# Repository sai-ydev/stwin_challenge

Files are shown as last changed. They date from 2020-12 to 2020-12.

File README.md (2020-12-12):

# STWIN Challenge submission - Low-Cost Sensor Hub for Anomaly Detection

This repo contains all the relevant information for our submission to the STWIN Challenge.

The Sensor Hub has the following variants: 

* Zigbee variant (Battery Powered)
  * ISM330DHCX
  * IIS2ICLX 
* Cellular variant (DC powered)
  * ISM330DHCX
  
## Applications

* Asset Tracking
* Anomaly Detection

## Project log - 12/11/2020

PCBs have arrived

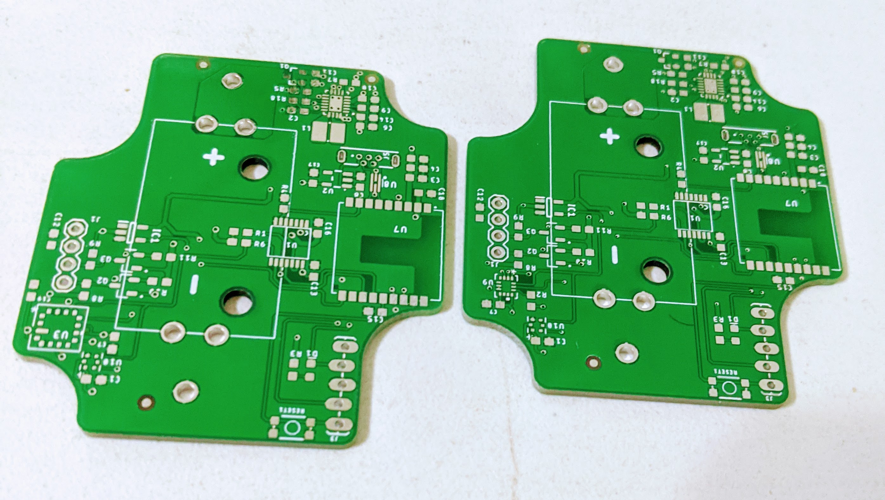
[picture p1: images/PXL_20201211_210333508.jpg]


## Project Log - 12/6/2020

PCBs sent to fabrication

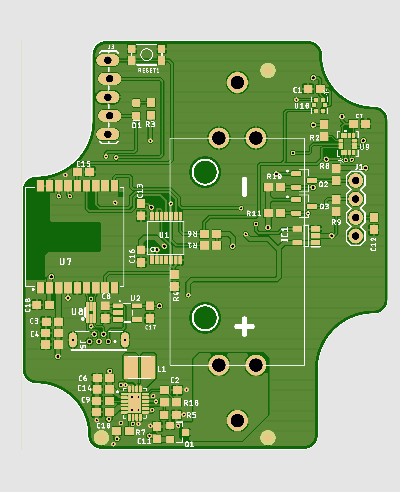
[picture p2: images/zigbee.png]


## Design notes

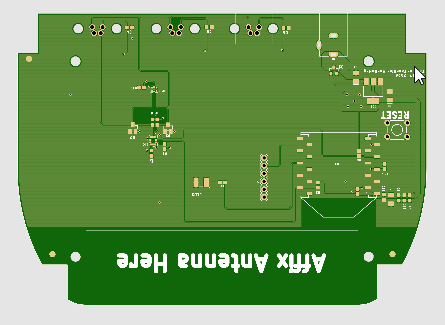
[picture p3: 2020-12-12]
images/cellular.png

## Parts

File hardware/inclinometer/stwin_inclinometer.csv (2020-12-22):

Part | Value | Device | Package | Description | AVAILABILITY | BUILT_BY | COPYRIGHT | DATASHEET | DESCRIPTION | DIGI-KEY_PART_NUMBER | HEIGHT | MANUFACTURER_NAME | MANUFACTURER_PART_NUMBER | MF | MOUSER_PART_NUMBER | MOUSER_PRICE-STOCK | MP | PACKAGE | PRICE | PROD_ID | PURCHASE-URL | SOURCELIBRARY | VALUE | VENDOR
BATT1 | KEYSTONE_54KEYSTONE_2 | KEYSTONE_54KEYSTONE_2 | KEYSTONE_V2
C1 | 0.1uF | 0.1UF-0603-25V-(+80/-20%) | 0603 | 0.1µF ceramic capacitors |  |  |  |  |  |  |  |  |  |  |  |  |  |  |  | CAP-00810 |  |  | 0.1uF
C2 | 10uF | 10UF-0603-6.3V-20% | 0603 | 10.0µF ceramic capacitors |  |  |  |  |  |  |  |  |  |  |  |  |  |  |  | CAP-11015 |  |  | 10uF
C3 | 560pF | 560PF-0603-50V-5% | 0603 | 0.56nF/560pF ceramic capacitors |  |  |  |  |  |  |  |  |  |  |  |  |  |  |  | CAP-08749 |  |  | 560pF
C4 | 10uF | 10UF-0603-6.3V-20% | 0603 | 10.0µF ceramic capacitors |  |  |  |  |  |  |  |  |  |  |  |  |  |  |  | CAP-11015 |  |  | 10uF
C5 | 10nF | 10NF-0603-50V-10% | 0603 | 0.01uF/10nF/10,000pF ceramic capacitors |  |  |  |  |  |  |  |  |  |  |  |  |  |  |  | CAP-00867 |  |  | 10nF
C6 | 10pF | 10PF-0603-50V-5% | 0603 | 10pF ceramic capacitors |  |  |  |  |  |  |  |  |  |  |  |  |  |  |  | CAP-11812 |  |  | 10pF
C7 | 0.1uF | 0.1UF-0603-25V-(+80/-20%) | 0603 | 0.1µF ceramic capacitors |  |  |  |  |  |  |  |  |  |  |  |  |  |  |  | CAP-00810 |  |  | 0.1uF
C8 | 1.0uF | 1.0UF-0603-16V-10% | 0603 | 1µF ceramic capacitors |  |  |  |  |  |  |  |  |  |  |  |  |  |  |  | CAP-00868 |  |  | 1.0uF
C9 | 2.2uF | 2.2UF-0603-10V-20% | 0603 | 2.2µF ceramic capacitors |  |  |  |  |  |  |  |  |  |  |  |  |  |  |  | CAP-07888 |  |  | 2.2uF
C10 | 10nF | 10NF-0603-50V-10% | 0603 | 0.01uF/10nF/10,000pF ceramic capacitors |  |  |  |  |  |  |  |  |  |  |  |  |  |  |  | CAP-00867 |  |  | 10nF
C11 | 47uF | 4.7UF0603 | 0603 | 4.7µF ceramic capacitors |  |  |  |  |  |  |  |  |  |  |  |  |  |  |  | CAP-08280 |  |  | 4.7uF
C12 | 0.1uF | 0.1UF-0603-25V-(+80/-20%) | 0603 | 0.1µF ceramic capacitors |  |  |  |  |  |  |  |  |  |  |  |  |  |  |  | CAP-00810 |  |  | 0.1uF
C13 | 0.1uF | 0.1UF-0603-25V-(+80/-20%) | 0603 | 0.1µF ceramic capacitors |  |  |  |  |  |  |  |  |  |  |  |  |  |  |  | CAP-00810 |  |  | 0.1uF
C14 | 47uF | 4.7UF0603 | 0603 | 4.7µF ceramic capacitors |  |  |  |  |  |  |  |  |  |  |  |  |  |  |  | CAP-08280 |  |  | 4.7uF
C15 | 10nF | 10NF-0603-50V-10% | 0603 | 0.01uF/10nF/10,000pF ceramic capacitors |  |  |  |  |  |  |  |  |  |  |  |  |  |  |  | CAP-00867 |  |  | 10nF
C16 | 0.1uF | 0.1UF-0603-25V-(+80/-20%) | 0603 | 0.1µF ceramic capacitors |  |  |  |  |  |  |  |  |  |  |  |  |  |  |  | CAP-00810 |  |  | 0.1uF
C17 | 1.0uF | 1.0UF-0603-16V-10% | 0603 | 1µF ceramic capacitors |  |  |  |  |  |  |  |  |  |  |  |  |  |  |  | CAP-00868 |  |  | 1.0uF
C18 | 1.0uF | 1.0UF-0603-16V-10% | 0603 | 1µF ceramic capacitors |  |  |  |  |  |  |  |  |  |  |  |  |  |  |  | CAP-00868 |  |  | 1.0uF
C19 | 0.1uF | 0.1UF-0603-25V-(+80/-20%) | 0603 | 0.1µF ceramic capacitors |  |  |  |  |  |  |  |  |  |  |  |  |  |  |  | CAP-00810 |  |  | 0.1uF
D1 | GREEN | LED-GREEN0603 | LED-0603 | Green SMD LED |  |  |  |  |  |  |  |  |  |  |  |  |  |  |  | DIO-00821 |  |  | GREEN
IC1 | NC7SZ66M5X | NC7SZ66M5X | SOT95P280X145-5N | NC7SZ66M5X, Analogue SPST Switch Single SPST, 3 V, 5 V, 5-Pin, SOT-23, 1 |  |  |  |  | NC7SZ66M5X, Analogue SPST Switch Single SPST, 3 V, 5 V, 5-Pin, SOT-23, 1 |  | 1.45mm | ON Semiconductor | NC7SZ66M5X |  | 512-NC7SZ66M5X | https://www.mouser.com/Search/Refine.aspx?Keyword=512-NC7SZ66M5X
J1 |  | I2C_STANDARD | 1X04 | SparkFun I2C Standard Pinout Header
J3 |  | CONN_05LOCK_LONGPADS | 1X05_LOCK_LONGPADS | Multi connection point. Often used as Generic Header-pin footprint for 0.1 inch spaced/style header connections
J5 | 614105150721 | 614105150721 | 614105150721 | WR-COM Micro USB 2.0 Type B Vertical 5 Contacts |  |  |  |  | USB - micro B USB 2.0 Receptacle Connector 5 Position Through Hole |  |  |  |  | Wurth Electronics |  |  | 614105150721 | None |  |  | https://pricing.snapeda.com/search/part/614105150721/?ref=eda
L1 | LQH3NPN100MMEL | LQH3NPN100MMEL | INDPM3030X150N | Fixed Inductors 10uH 1280mA 0.228ohm SRF=20MHz(min) |  |  |  |  | Fixed Inductors 10uH 1280mA 0.228ohm SRF=20MHz(min) |  | 1.5mm | Murata Electronics | LQH3NPN100MMEL |  | 81-LQH3NPN100MMEL | https://www.mouser.com/Search/Refine.aspx?Keyword=81-LQH3NPN100MMEL
Q1 | 2.5A/30V/105mΩ | MOSFET_PCH-DMG2307L | SOT23-3 | P-channel MOSFETs |  |  |  |  |  |  |  |  |  |  |  |  |  |  |  | TRANS-11308 |  |  | 2.5A/30V/105mΩ
Q2 | BSS138 | BSS138 | SOT95P240X111-3N | N-Channel 50V 220mA (Ta) 360mW (Ta) Surface Mount SOT-23-3 Check prices | Good |  |  |  | N-Channel 50V 220mA (Ta) 360mW (Ta) Surface Mount SOT-23-3 |  |  |  |  | ON Semiconductor |  |  | BSS138 | SOT-23 ON Semiconductor | None |  | https://pricing.snapeda.com/search/part/BSS138/?ref=eda
Q3 | BSS138 | BSS138 | SOT95P240X111-3N | N-Channel 50V 220mA (Ta) 360mW (Ta) Surface Mount SOT-23-3 Check prices | Good |  |  |  | N-Channel 50V 220mA (Ta) 360mW (Ta) Surface Mount SOT-23-3 |  |  |  |  | ON Semiconductor |  |  | BSS138 | SOT-23 ON Semiconductor | None |  | https://pricing.snapeda.com/search/part/BSS138/?ref=eda
R1 | 4.7k | 4.7KOHM-0603-1/10W-1% | 0603 | 4.7kΩ resistor |  |  |  |  |  |  |  |  |  |  |  |  |  |  |  | RES-07857 |  |  | 4.7k
R3 | 1k | 1KOHM-0603-1/10W-1% | 0603 | 1kΩ resistor |  |  |  |  |  |  |  |  |  |  |  |  |  |  |  | RES-07856 |  |  | 1k
R4 | 10M | 10MOHM-0603-1/10W-5% | 0603 | RES-09327 |  |  |  |  |  |  |  |  |  |  |  |  |  |  |  | RES-08283 |  |  | 10M
R5 | 365k | 348KOHM-0603-1/10W-1% | 0603 | 348kΩ resistor |  |  |  |  |  |  |  |  |  |  |  |  |  |  |  | RES-12533 |  |  | 348k
R6 | 4.7k | 4.7KOHM-0603-1/10W-1% | 0603 | 4.7kΩ resistor |  |  |  |  |  |  |  |  |  |  |  |  |  |  |  | RES-07857 |  |  | 4.7k
R7 | 10M | 10MOHM-0603-1/10W-5% | 0603 | RES-09327 |  |  |  |  |  |  |  |  |  |  |  |  |  |  |  | RES-08283 |  |  | 10M
R8 | 4.7k | 4.7KOHM-0603-1/10W-1% | 0603 | 4.7kΩ resistor |  |  |  |  |  |  |  |  |  |  |  |  |  |  |  | RES-07857 |  |  | 4.7k
R9 | 4.7k | 4.7KOHM-0603-1/10W-1% | 0603 | 4.7kΩ resistor |  |  |  |  |  |  |  |  |  |  |  |  |  |  |  | RES-07857 |  |  | 4.7k
R10 | 4.7k | 4.7KOHM-0603-1/10W-1% | 0603 | 4.7kΩ resistor |  |  |  |  |  |  |  |  |  |  |  |  |  |  |  | RES-07857 |  |  | 4.7k
R11 | 4.7k | 4.7KOHM-0603-1/10W-1% | 0603 | 4.7kΩ resistor |  |  |  |  |  |  |  |  |  |  |  |  |  |  |  | RES-07857 |  |  | 4.7k
R18 | 2M | 1MOHM-0603-1/4W-5% | 0603 | 1MΩ resistor |  |  |  |  |  |  |  |  |  |  |  |  |  |  |  | RES-07868 |  |  | 1M
RESET1 |  | MOMENTARY-SWITCH-SPST-2-SMD-4.6X2.8MM | TACTILE_SWITCH_SMD_4.6X2.8MM | Momentary Switch (Pushbutton) - SPST - Two Circuits |  |  |  |  |  |  |  |  |  |  |  |  |  |  |  | SWCH-13065
U$5 | FIDUCIAL | FIDUCIAL | FIDUCIAL_1MM | For use by pick and place machines to calibrate the vision/machine, 1mm
U$6 | FIDUCIAL | FIDUCIAL | FIDUCIAL_1MM | For use by pick and place machines to calibrate the vision/machine, 1mm
U$7 | FIDUCIAL | FIDUCIAL | FIDUCIAL_1MM | For use by pick and place machines to calibrate the vision/machine, 1mm
U1 | TS3A4751 | TS3A4751 | 14_PIN | TS3A4751 Quad Switch | Unavailable |  |  |  | 0.9 Ohm Low-Voltage Single-Supply Quad SPST Analog Switch |  |  |  |  | Texas Instruments |  |  | TS3A4751 | TSSOP-14 Texas Instruments | None
U2 | 3.3V | V_REG_AP2112K-3.3V | SOT23-5 | AP2112 - 600mA CMOS LDO Regulator w/ Enable |  |  |  |  |  |  |  |  |  |  |  |  |  |  |  | VREG-12457 |  |  | 3.3V
U3 | IIS2ICLXTR | IIS2ICLXTR | QFN_ICLX_STM |  |  | EMA_Matt | Copyright (C) 2018 Accelerated Designs. All rights reserved | https://www.st.com/resource/en/datasheet/iis2iclx.pdf |  |  |  |  | IIS2ICLXTR |  |  |  |  |  |  |  |  | Updates_to_database_2020-11-03 |  | STMicroelectronics
U4 | LTC3106EUDC#TRPBF | LTC3106EUDC#TRPBF | QFN50P400X300X80-21N | LTC3106 - 300mA Low Voltage Buck-Boost Converter with PowerPath and 1.6μA Quiescent Current | Unavailable |  |  |  | LTC3106 - 300mA Low Voltage Buck-Boost Converter with PowerPath and 1.6μA Quiescent Current |  |  |  |  | Linear Technology/Analog |  |  | LTC3106EUDC#TRPBF | QFN-20 Linear Technology | None
U7 | STEVAL-STLCS01V1 | STEVAL-STLCS01V1 | XDCR_STEVAL-STLCS01V1 | Evaluation kit based on the STM32L476JGY6TR, LSM303AGRTR, LSM6DSMTR, BlueNRG-MSCSP, LPS22HBTR, MP34DT04 and BALF-NRG | Unavailable |  |  |  | BlueNRG-MS, LPS22HB, LSM6DSM, LSM303AGR, MP34DT04, STM32L4 SensorTile Accelerometer, Gyroscope, Humidity, Magnetometer, Pressure, Temperature Sensor Evaluation Board |  |  |  |  | STMicroelectronics |  |  | STEVAL-STLCS01V1 | None | None
U8 | USBLC6-2 | USBLC6-2 | USBLC6-2P6 |  | Unavailable |  |  |  | 17V Clamp 5A (8/20µs) Ipp Tvs Diode Surface Mount SOT-23-6 |  |  |  |  | STMicroelectronics |  |  | USBLC6-2 | SOT-563 STMicroelectronics | None
U10 | HTS221TRHLGA-6L_2X2_STM-M | HTS221TRHLGA-6L_2X2_STM-M | HLGA-6L_2X2_STM-M |  |  | EMA_Anthony | Copyright (C) 2018 Accelerated Designs. All rights reserved | https://www.st.com/content/ccc/resource/technical/document/datasheet/4d/9a/9c/ad/25/07/42/34/DM00116291.pdf/files/DM00116291.pdf/jcr:content/translations/en.D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 |  |  |  |  | HTS221TR |  |  |  |  |  |  |  |  | Updates_to_database_2020-11-03 |  | STMicroelectronics

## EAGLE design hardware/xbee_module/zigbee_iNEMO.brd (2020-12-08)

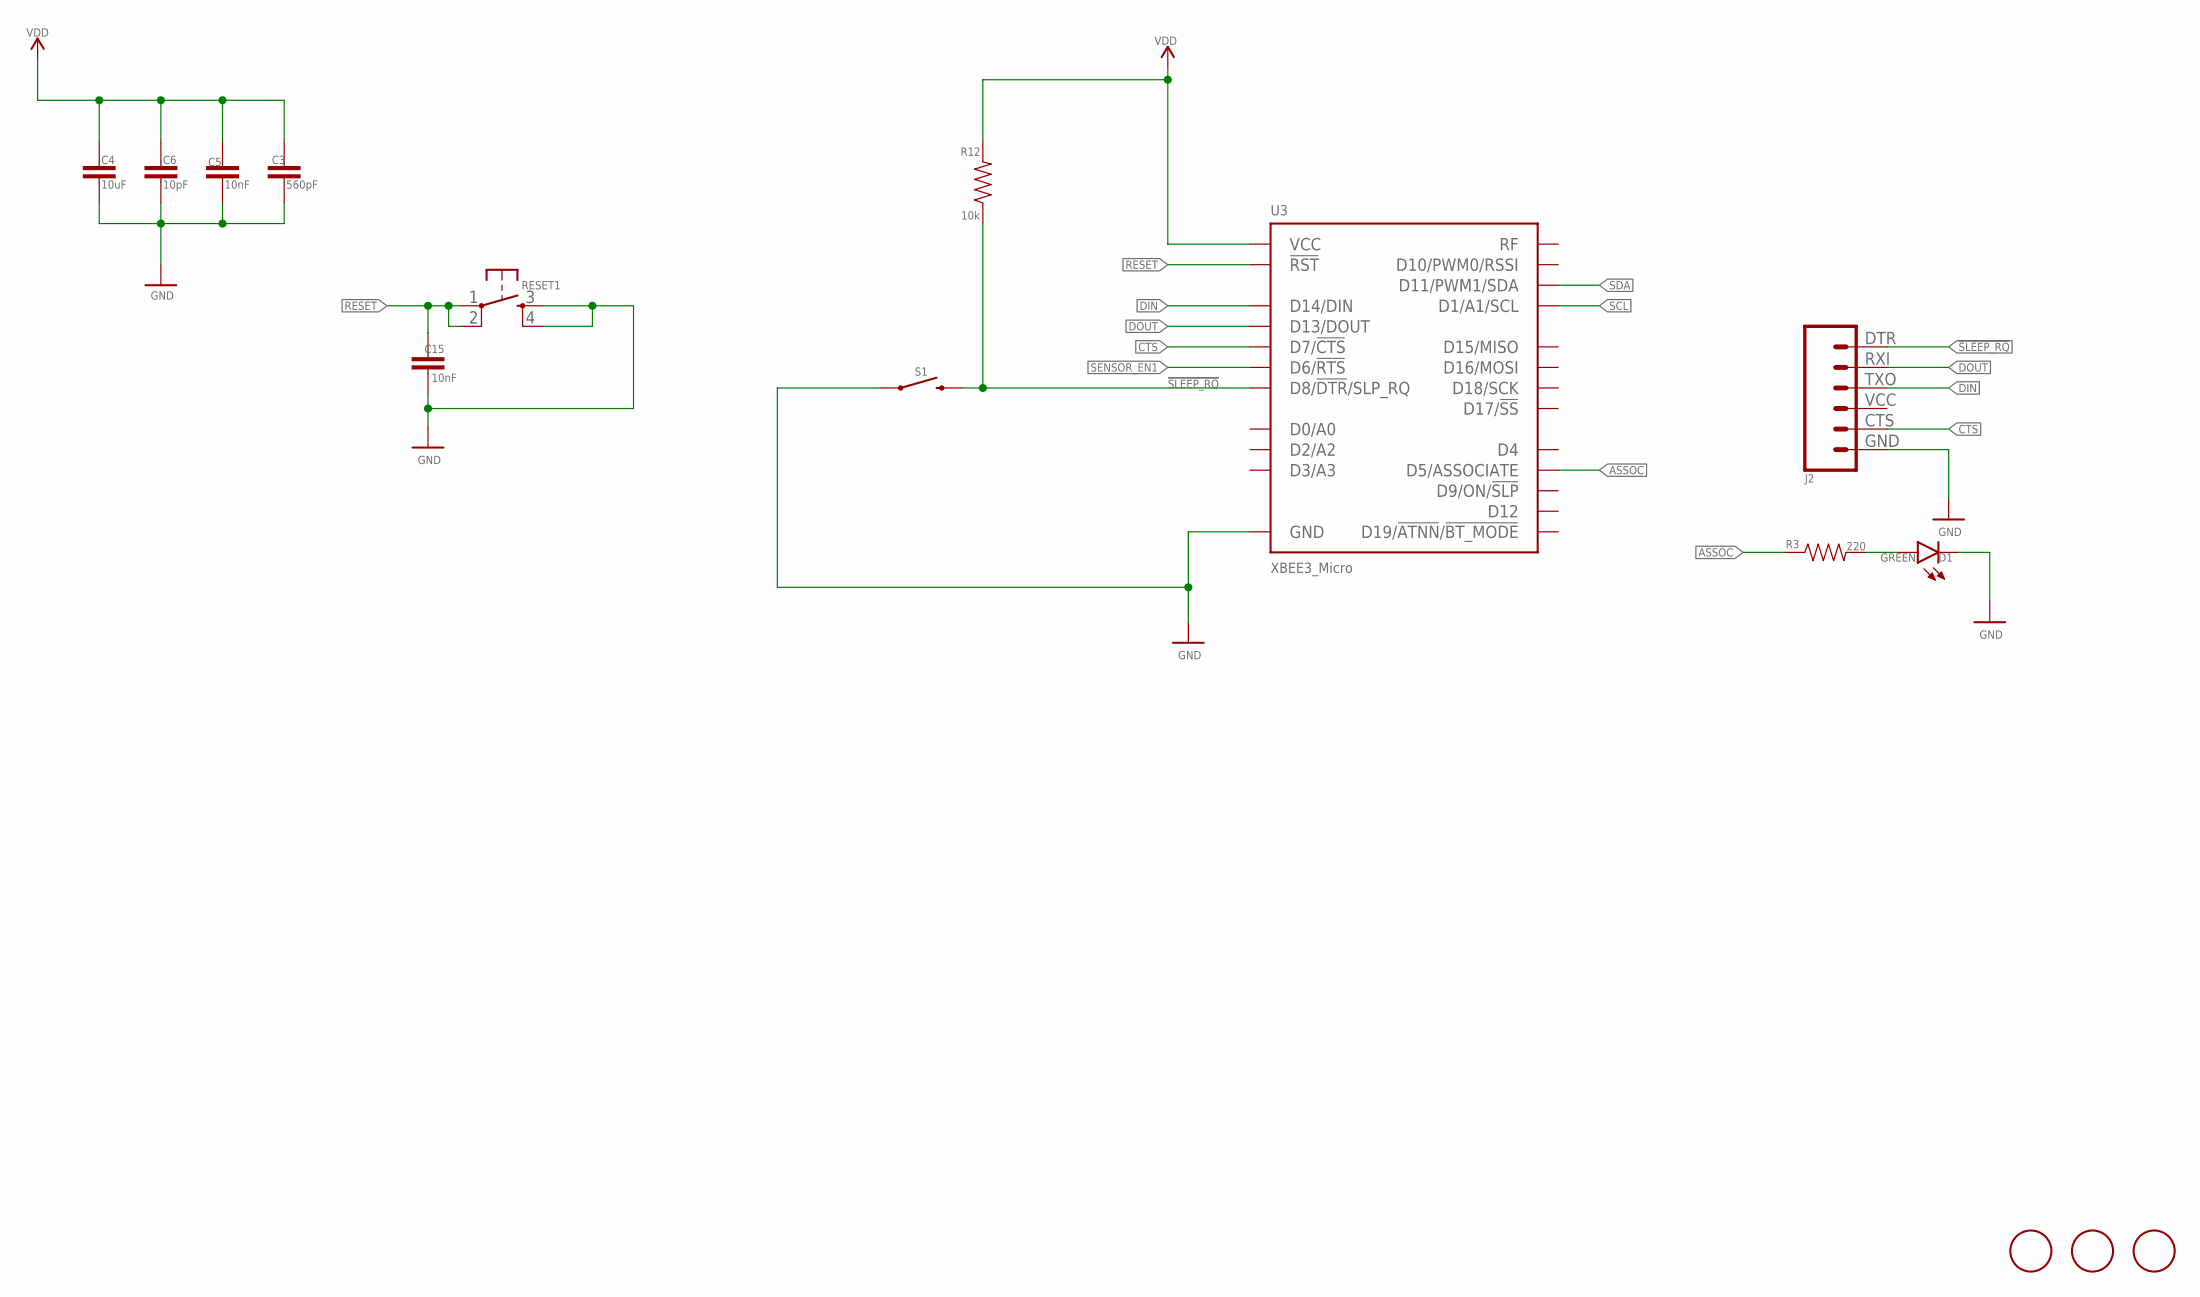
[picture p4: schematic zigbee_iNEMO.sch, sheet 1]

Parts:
C3: 560pF; 0603
C4: 10uF; 0603
C5, C15: 10nF; 0603
C6: 10pF; 0603
D1: GREEN; LED-0603
J2: 6_PIN_SERIAL_CABLEPTH; FTDI_BASIC
R3: 220; 0603
R12: 10k; 0603
RESET1: MOMENTARY-SWITCH-SPST-2-SMD-4.6X2.8MM; TACTILE_SWITCH_SMD_4.6X2.8MM
S1: MOMENTARY-SWITCH-SPST-SMD-4.6X2.8MM; TACTILE_SWITCH_SMD_4.6X2.8MM
U3: XBEE3_Micro; XBEE3_THING_PLUS_SPARKFUN-RF_XBEE3
U$5, U$6, U$7: FIDUCIAL; FIDUCIAL_1MM

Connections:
!SLEEP_RQ: J2.DTR (1), R12.1, S1.3 (2), S1.4 (2), U3.P$9 (D8/!DTR!/SLP_RQ)
ASSOC: R3.1, U3.P$26 (D5/ASSOCIATE)
CTS: J2.CTS (5), U3.P$24 (D7/!CTS)
DIN: J2.TXO (3), U3.P$4 (D14/DIN)
DOUT: J2.RXI (2), U3.P$3 (D13/DOUT)
GND: C3.1, C4.1, C5.1, C6.1, C15.1, D1.C, J2.GND (6), RESET1.3, RESET1.4, S1.1, S1.2 (1), U3.P$1 (GND), U3.P$10 (GND), U3.P$12 (GND), U3.P$21 (GND), U3.P$32 (GND), U3.P$34 (GND); also elsewhere on the board
unnamed: D1.A, R3.2
RESET: C15.2, RESET1.1, RESET1.2, U3.P$6 (!RST)
SCL: U3.P$30 (D1/A1/SCL); also elsewhere on the board
SDA: U3.P$8 (D11/PWM1/SDA); also elsewhere on the board
SENSOR_EN1: U3.P$27 (D6/!RTS); also elsewhere on the board
VDD: C3.2, C4.2, C5.2, C6.2, R12.2, U3.P$2 (VCC); also elsewhere on the board

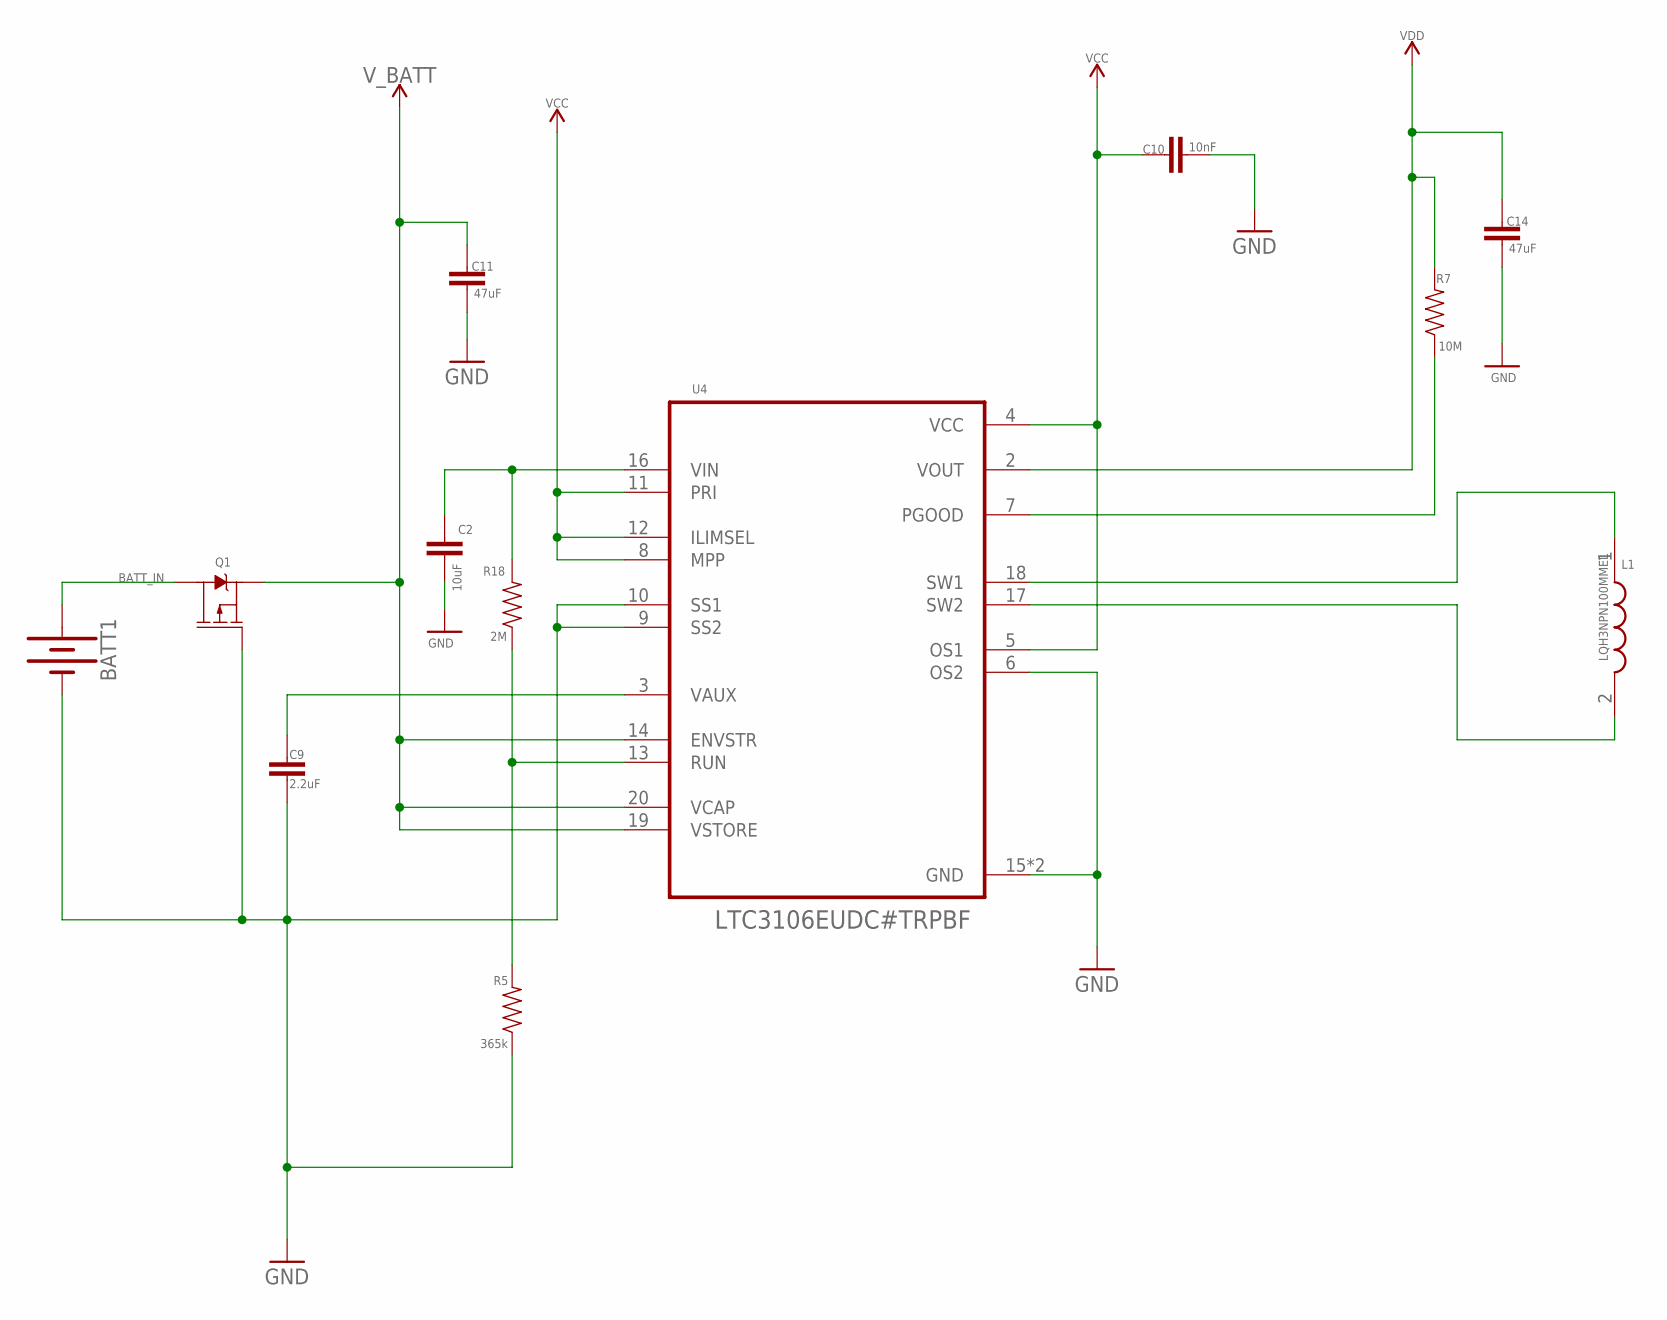
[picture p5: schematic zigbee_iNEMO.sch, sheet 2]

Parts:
BATT1: KEYSTONE_54KEYSTONE_2; KEYSTONE_V2
C2: 10uF; 0603
C9: 2.2uF; 0603
C10: 10nF; 0603
C11, C14: 47uF; 0603
L1: LQH3NPN100MMEL; INDPM3030X150N
Q1: 2.5A/30V/105mΩ; SOT23-3
R5: 365k; 0603
R7: 10M; 0603
R18: 2M; 0603
U4: LTC3106EUDC#TRPBF; QFN50P400X300X80-21N

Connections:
BATT_IN: BATT1.P$1 (+), BATT1.P$2 (+), BATT1.P$3 (+), Q1.3 (D)
GND: BATT1.P$4 (-), BATT1.P$5 (-), BATT1.P$6 (-), C2.2, C9.2, C10.2, C11.2, C14.2, Q1.1 (G), R5.1, U4.6 (OS2), U4.9 (SS2), U4.10 (SS1), U4.15 (GND), U4.21 (GND); also elsewhere on the board
unnamed: L1.1, U4.18 (SW1)
unnamed: L1.2, U4.17 (SW2)
unnamed: R7.1, U4.7 (PGOOD)
unnamed: C9.1, U4.3 (VAUX)
unnamed: C2.1, R18.2, U4.16 (VIN)
unnamed: R5.2, R18.1, U4.13 (RUN)
VCC: C10.1, U4.4 (VCC), U4.5 (OS1), U4.8 (MPP), U4.11 (PRI), U4.12 (ILIMSEL)
VDD: C14.1, R7.2, U4.2 (VOUT); also elsewhere on the board
V_BATT: C11.1, Q1.2 (S), U4.14 (ENVSTR), U4.19 (VSTORE), U4.20 (VCAP)

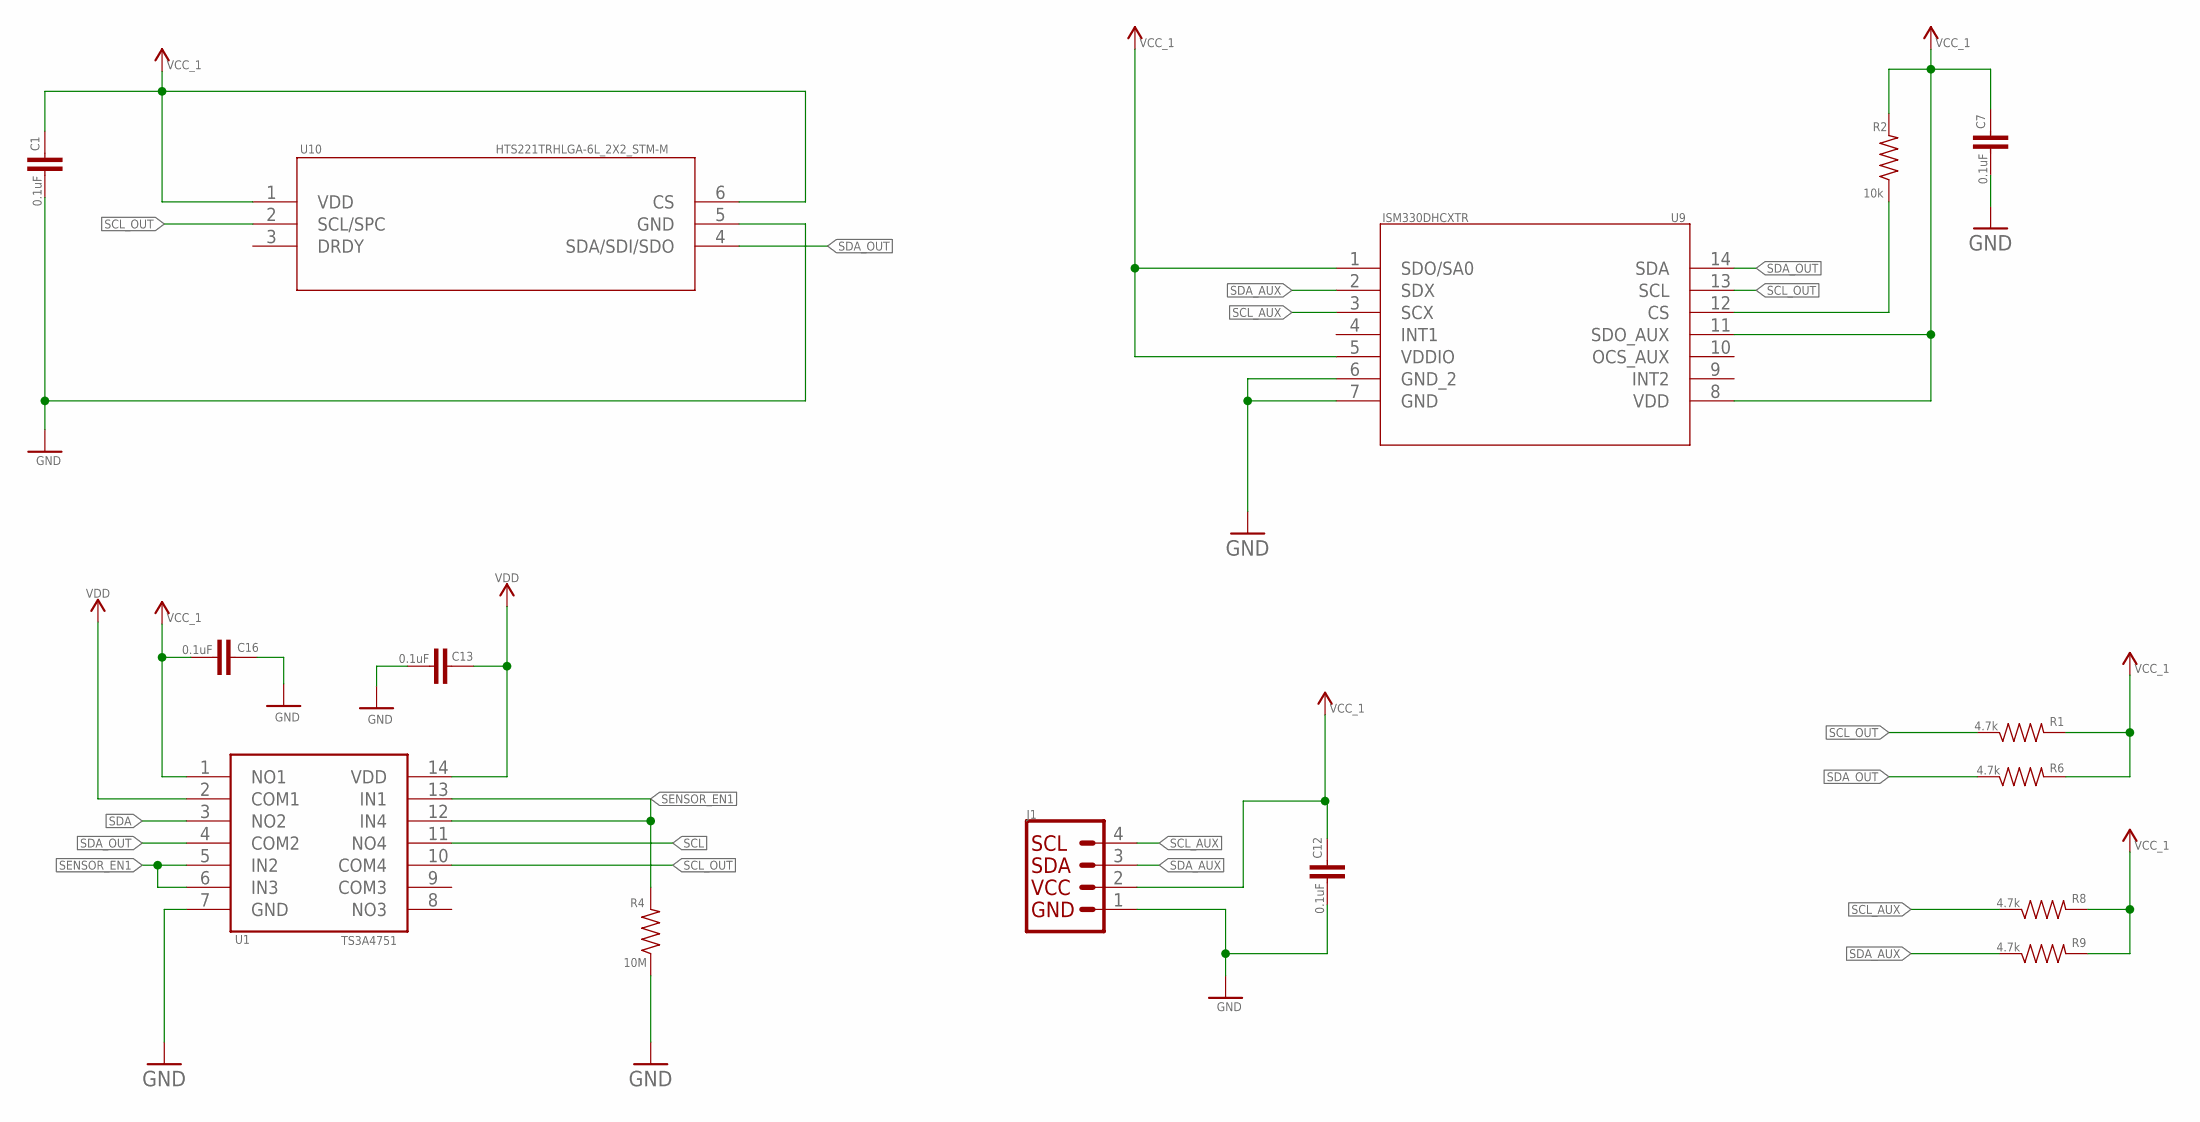
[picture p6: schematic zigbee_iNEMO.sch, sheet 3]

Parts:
C1, C7, C12, C13, C16: 0.1uF; 0603
J1: I2C_STANDARD; 1X04
R1, R6, R8, R9: 4.7k; 0603
R2: 10k; 0603
R4: 10M; 0603
U1: TS3A4751; 14_PIN
U9: ISM330DHCXTR; QFN_DHCXTR_STM
U10: HTS221TRHLGA-6L_2X2_STM-M; HLGA-6L_2X2_STM-M

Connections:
GND: C1.2, C7.2, C12.2, C13.2, C16.1, J1.1, R4.1, U1.7 (GND), U9.6 (GND_2), U9.7 (GND), U10.5 (GND); also elsewhere on the board
unnamed: R2.1, U9.12 (CS)
SCL: U1.11 (NO4); also elsewhere on the board
SCL_AUX: J1.4, R8.1, U9.3 (SCX)
SCL_OUT: R1.1, U1.10 (COM4), U9.13 (SCL), U10.2 (SCL/SPC)
SDA: U1.3 (NO2); also elsewhere on the board
SDA_AUX: J1.3, R9.1, U9.2 (SDX)
SDA_OUT: R6.1, U1.4 (COM2), U9.14 (SDA), U10.4 (SDA/SDI/SDO)
SENSOR_EN1: R4.2, U1.5 (IN2), U1.6 (IN3), U1.12 (IN4), U1.13 (IN1); also elsewhere on the board
VCC_1: C1.1, C7.1, C12.1, C16.2, J1.2, R1.2, R2.2, R6.2, R8.2, R9.2, U1.1 (NO1), U9.1 (SDO/SA0), U9.5 (VDDIO), U9.8 (VDD), U9.11 (SDO_AUX), U10.1 (VDD), U10.6 (CS)
VDD: C13.1, U1.2 (COM1), U1.14 (VDD); also elsewhere on the board

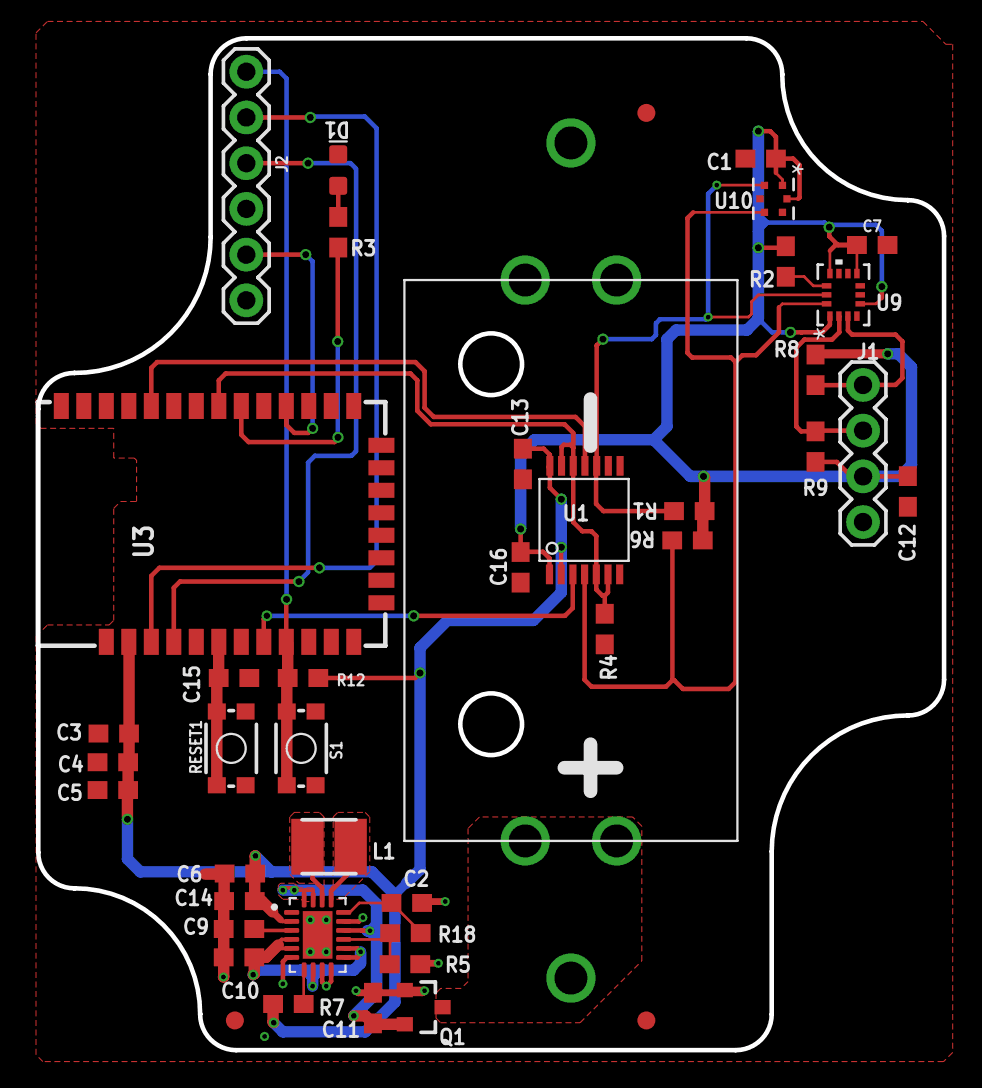
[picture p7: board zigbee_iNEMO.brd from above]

Board: 2 copper layers, 50.3 x 56.2 mm, 42 parts (0 on the bottom side), 27 nets.

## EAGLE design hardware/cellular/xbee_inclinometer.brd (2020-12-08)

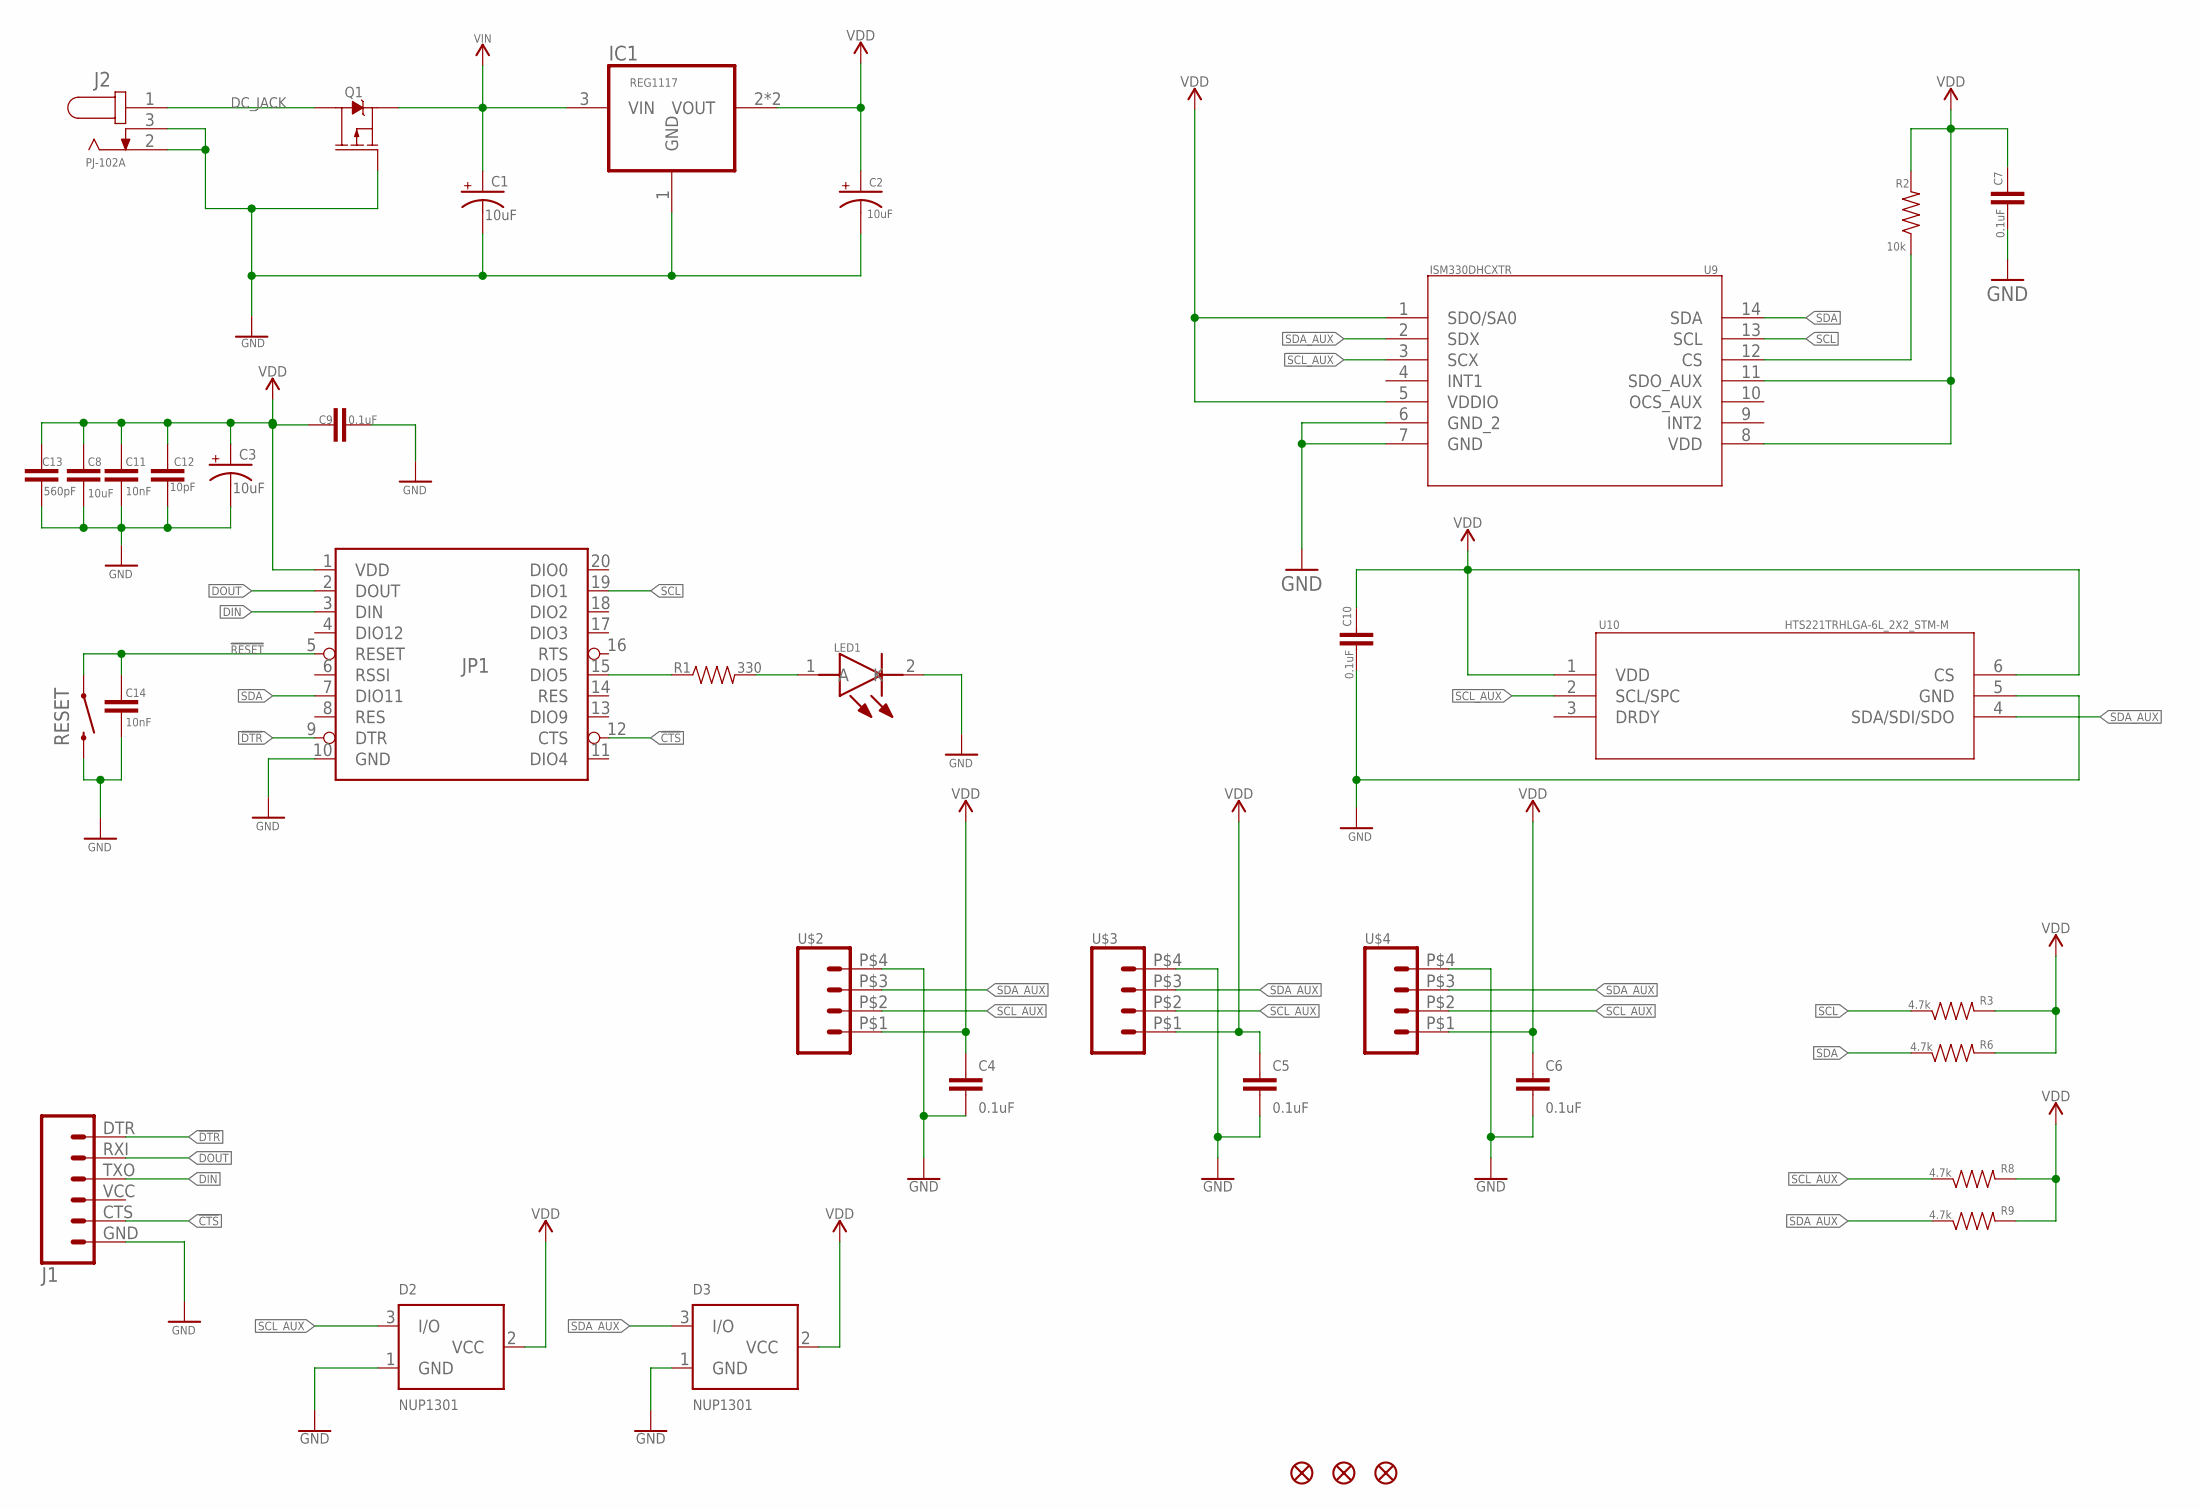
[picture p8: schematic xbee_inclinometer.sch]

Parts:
C1, C2, C3: 10uF; EIA3216
C4, C5, C6, C7, C9, C10: 0.1uF; 0603
C8: 10uF; 0603
C11, C14: 10nF; 0603
C12: 10pF; 0603
C13: 560pF; 0603
D2, D3: NUP1301; NUP1301_SOT-23
FID1, FID2, FID4: MICROBUILDER_FIDUCIAL""; MICROBUILDER_FIDUCIAL_1MM
IC1: REG1117; SOT223
J1: 6_PIN_SERIAL_CABLEPTH; FTDI_BASIC
J2: PJ-102A; CUI_PJ-102A
JP1: XBEESMD; XBEE-SMD
LED1: SMTL2-UWD; SMTL2UWD
Q1: 2.5A/30V/105mΩ; SOT23-3
R1: 330; 0603
R2: 10k; 0603
R3, R6, R8, R9: 4.7k; 0603
RESET: MOMENTARY-SWITCH-SPST-PTH-6.0MM; TACTILE_SWITCH_PTH_6.0MM
U9: ISM330DHCXTR; QFN_DHCXTR_STM
U10: HTS221TRHLGA-6L_2X2_STM-M; HLGA-6L_2X2_STM-M
U$2, U$3, U$4: RIGHT_ANGLED_DCFRECONN; M8_FRECONN

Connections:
!CTS: J1.CTS (5), JP1.12 (CTS)
!DTR: J1.DTR (1), JP1.9 (DTR)
!RESET: C14.1, JP1.5 (RESET), RESET.1
DC_JACK: J2.1, Q1.3 (D)
DIN: J1.TXO (3), JP1.3 (DIN)
DOUT: J1.RXI (2), JP1.2 (DOUT)
GND: C1.-, C2.-, C3.-, C4.2, C5.2, C6.2, C7.2, C8.2, C9.1, C10.2, C11.2, C12.2, C13.2, C14.2, D2.1 (GND), D3.1 (GND), IC1.1 (GND), J1.GND (6), J2.2, J2.3, JP1.10 (GND), LED1.2 (K), Q1.1 (G), RESET.3 (2), U9.6 (GND_2), U9.7 (GND), U10.5 (GND), U$2.P$4 (GND), U$3.P$4 (GND), U$4.P$4 (GND)
unnamed: JP1.15 (DIO5), R1.1
unnamed: LED1.1 (A), R1.2
unnamed: R2.1, U9.12 (CS)
SCL: JP1.19 (DIO1), R3.1, U9.13 (SCL)
SCL_AUX: D2.3 (I/O), R8.1, U9.3 (SCX), U10.2 (SCL/SPC), U$2.P$2 (SCL), U$3.P$2 (SCL), U$4.P$2 (SCL)
SDA: JP1.7 (DIO11), R6.1, U9.14 (SDA)
SDA_AUX: D3.3 (I/O), R9.1, U9.2 (SDX), U10.4 (SDA/SDI/SDO), U$2.P$3 (SDA), U$3.P$3 (SDA), U$4.P$3 (SDA)
VDD: C2.+, C3.+, C4.1, C5.1, C6.1, C7.1, C8.1, C9.2, C10.1, C11.1, C12.1, C13.1, D2.2 (VCC), D3.2 (VCC), IC1.2 (VOUT), IC1.4 (VOUT), JP1.1 (VDD), R2.2, R3.2, R6.2, R8.2, R9.2, U9.1 (SDO/SA0), U9.5 (VDDIO), U9.8 (VDD), U9.11 (SDO_AUX), U10.1 (VDD), U10.6 (CS), U$2.P$1 (VCC), U$3.P$1 (VCC), U$4.P$1 (VCC)
VIN: C1.+, IC1.3 (VIN), Q1.2 (S)

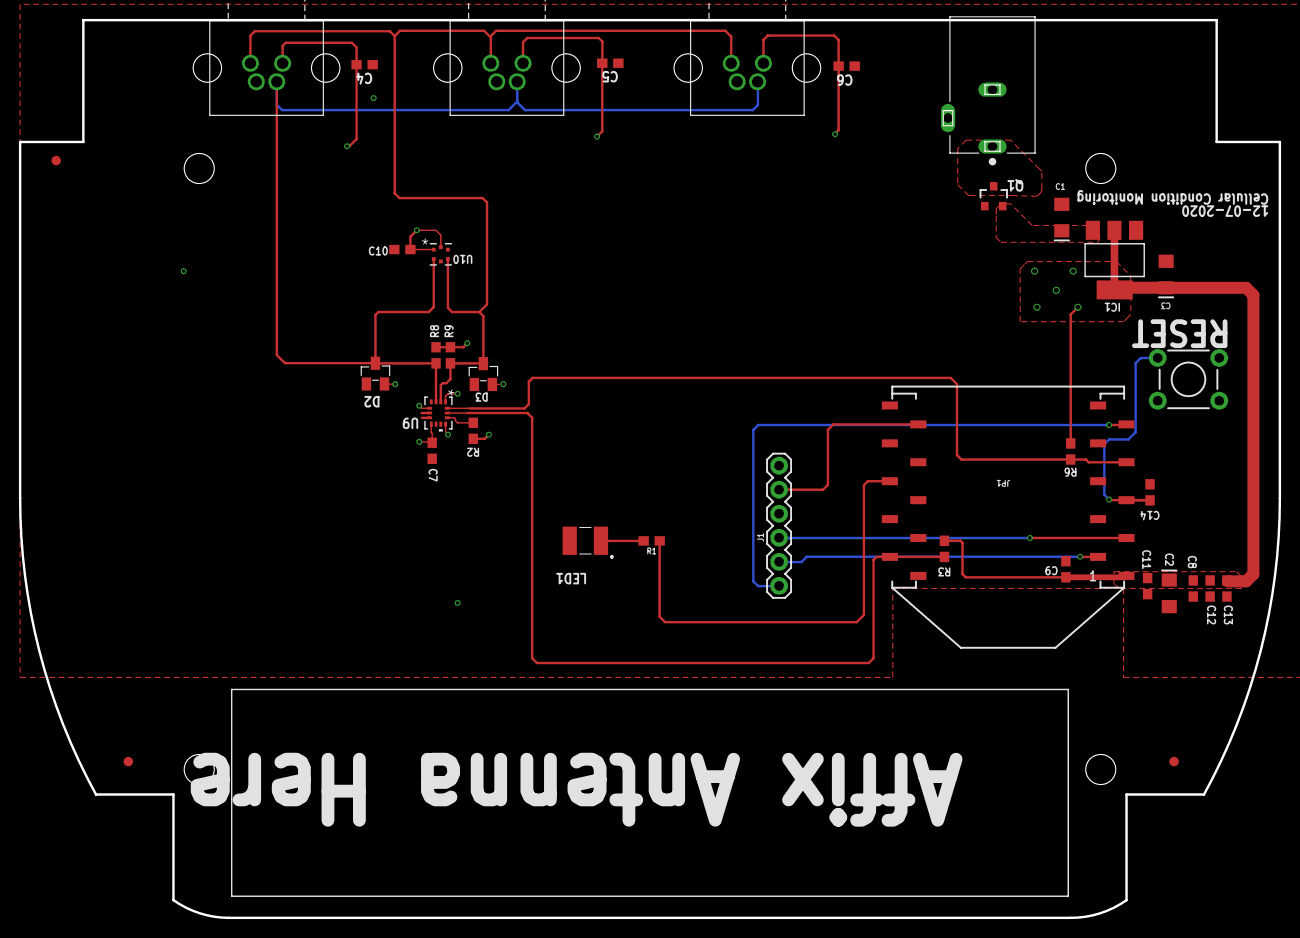
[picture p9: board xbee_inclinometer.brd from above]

Board: 2 copper layers, 133.1 x 94.8 mm, 37 parts (0 on the bottom side), 16 nets.

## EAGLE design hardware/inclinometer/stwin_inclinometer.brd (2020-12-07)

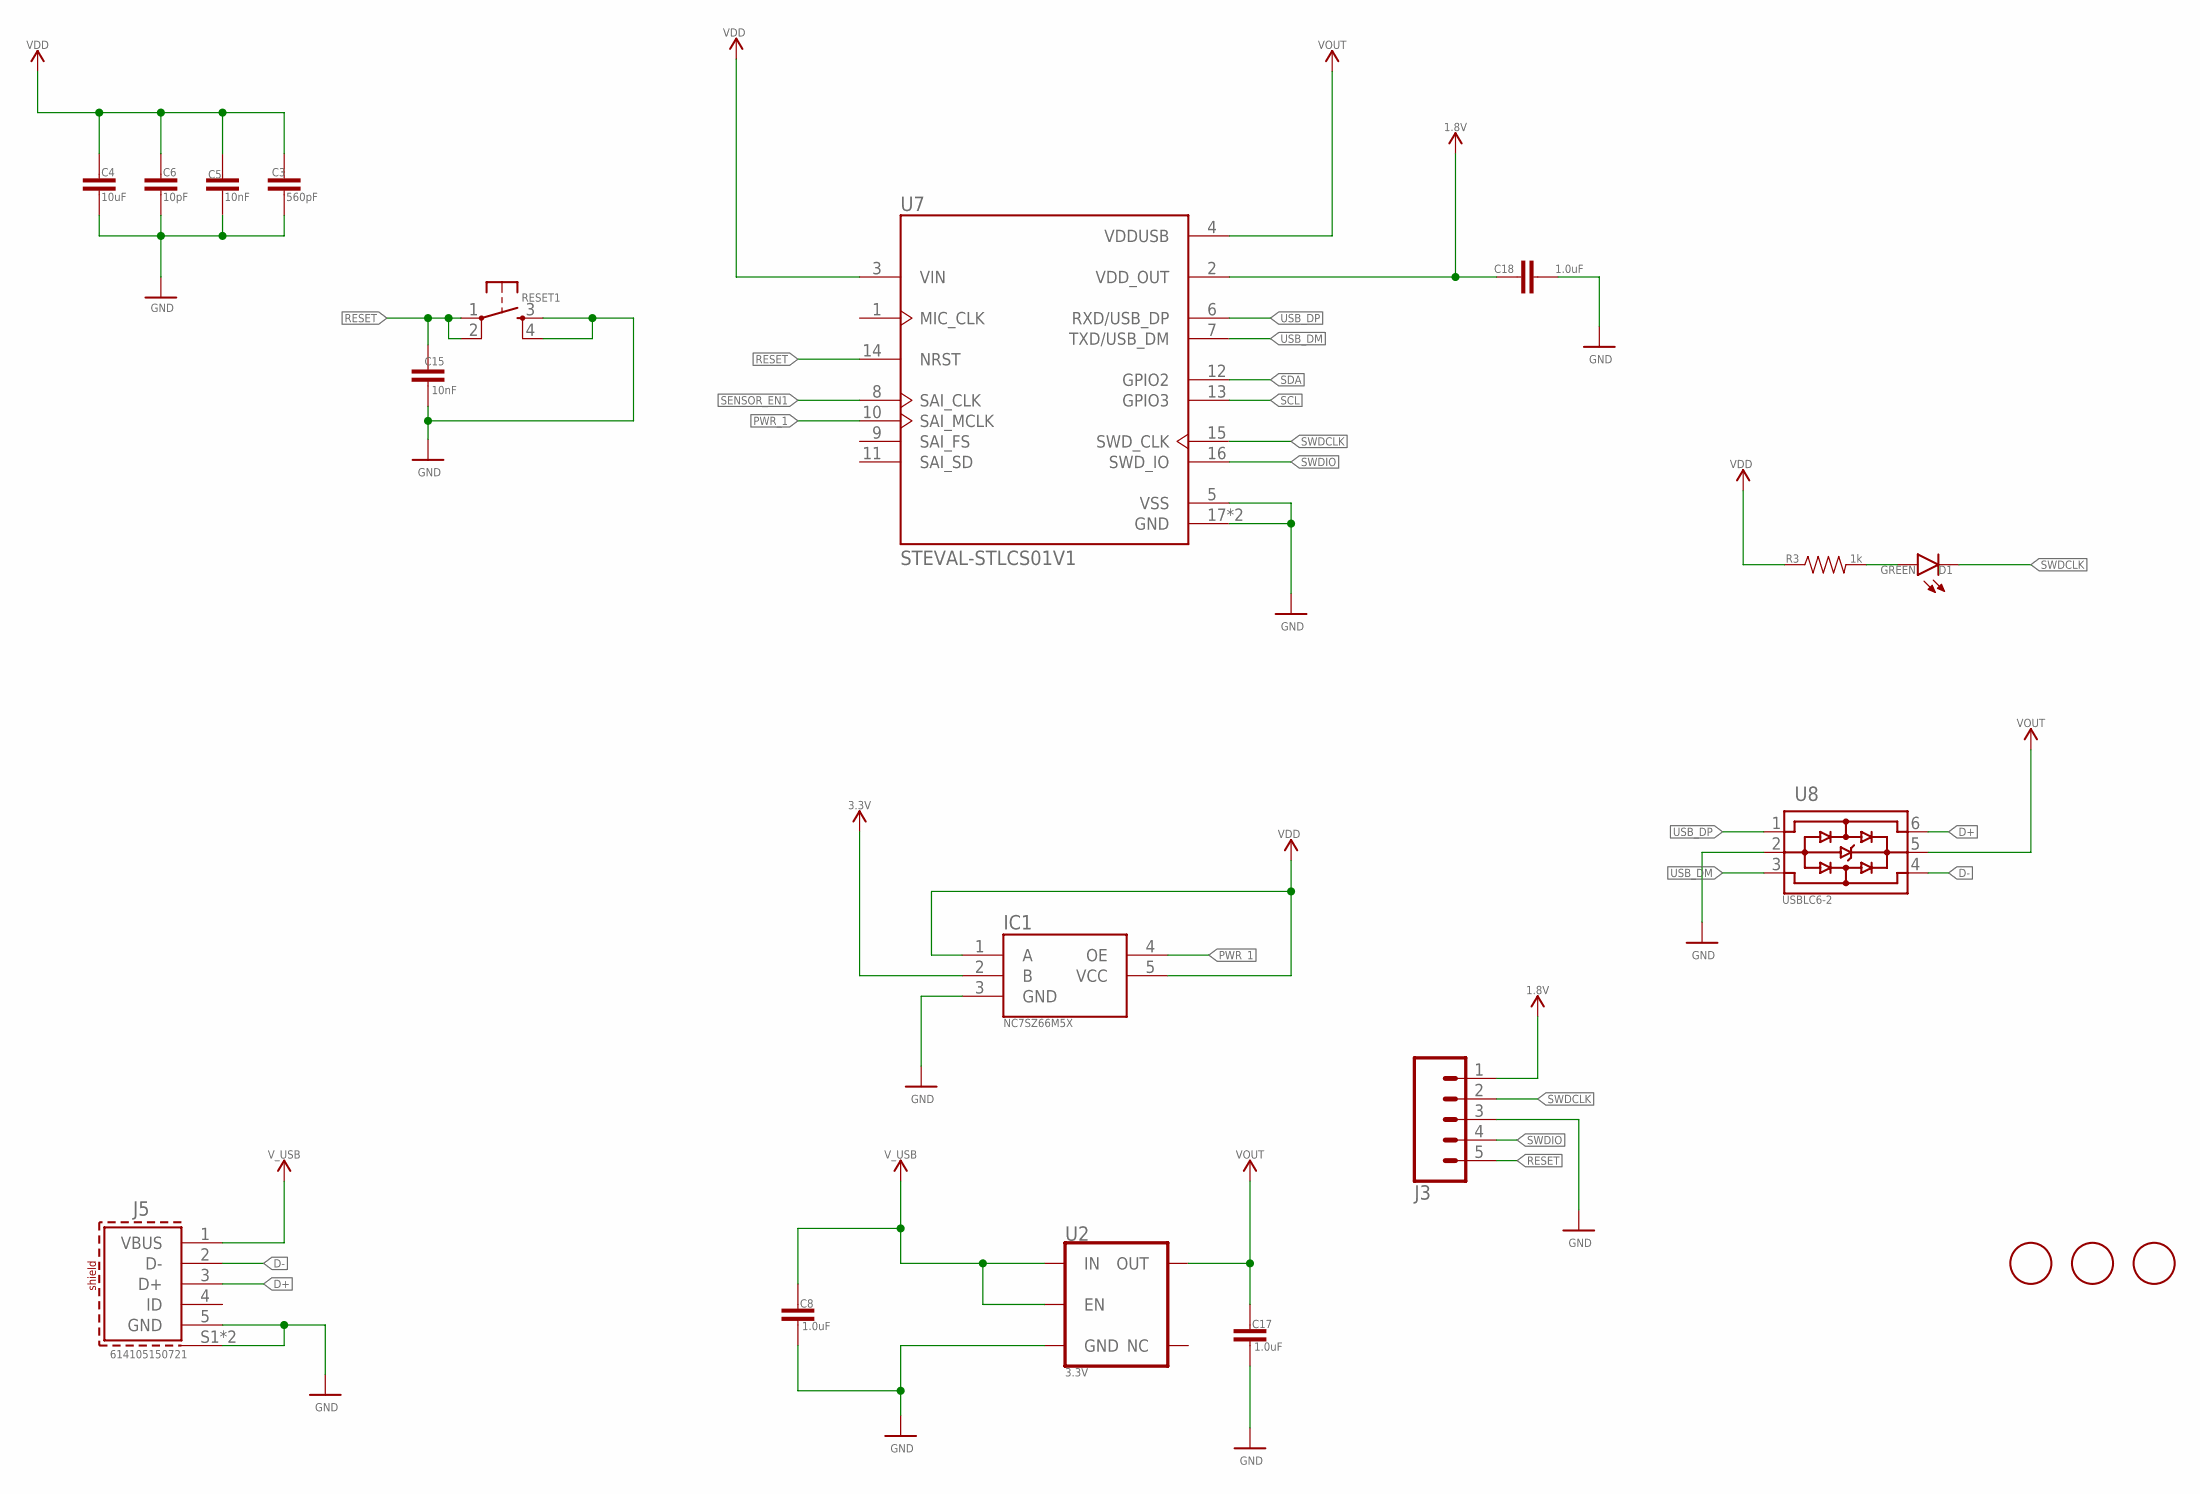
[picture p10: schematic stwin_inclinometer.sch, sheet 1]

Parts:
C3: 560pF; 0603
C4: 10uF; 0603
C5, C15: 10nF; 0603
C6: 10pF; 0603
C8, C17, C18: 1.0uF; 0603
D1: GREEN; LED-0603
IC1: NC7SZ66M5X; SOT95P280X145-5N
J3: CONN_05LOCK_LONGPADS; 1X05_LOCK_LONGPADS
J5: 614105150721
R3: 1k; 0603
RESET1: MOMENTARY-SWITCH-SPST-2-SMD-4.6X2.8MM; TACTILE_SWITCH_SMD_4.6X2.8MM
U2: 3.3V; SOT23-5
U7: STEVAL-STLCS01V1; XDCR_STEVAL-STLCS01V1
U8: USBLC6-2; USBLC6-2P6
U$5, U$6, U$7: FIDUCIAL; FIDUCIAL_1MM

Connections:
1.8V: C18.1, J3.1, U7.2 (VDD_OUT); also elsewhere on the board
3.3V: IC1.2 (B); also elsewhere on the board
D+: J5.3 (D+), U8.6
D-: J5.2 (D-), U8.4
GND: C3.1, C4.1, C5.1, C6.1, C8.2, C15.1, C17.2, C18.2, IC1.3 (GND), J3.3, J5.5 (GND), J5.S1 (SHIELD), J5.S2 (SHIELD), RESET1.3, RESET1.4, U2.2 (GND), U7.5 (VSS), U7.17 (GND), U7.18 (GND), U8.2; also elsewhere on the board
unnamed: D1.A, R3.2
PWR_1: IC1.4 (OE), U7.10 (SAI_MCLK)
RESET: C15.2, J3.5, RESET1.1, RESET1.2, U7.14 (NRST)
SCL: U7.13 (GPIO3); also elsewhere on the board
SDA: U7.12 (GPIO2); also elsewhere on the board
SENSOR_EN1: U7.8 (SAI_CLK); also elsewhere on the board
SWDCLK: D1.C, J3.2, U7.15 (SWD_CLK)
SWDIO: J3.4, U7.16 (SWD_IO)
USB_DM: U7.7 (TXD/USB_DM), U8.3
USB_DP: U7.6 (RXD/USB_DP), U8.1
VDD: C3.2, C4.2, C5.2, C6.2, IC1.1 (A), IC1.5 (VCC), R3.1, U7.3 (VIN); also elsewhere on the board
VOUT: C17.1, U2.5 (OUT), U7.4 (VDDUSB), U8.5
V_USB: C8.1, J5.1 (VBUS), U2.1 (IN), U2.3 (EN)

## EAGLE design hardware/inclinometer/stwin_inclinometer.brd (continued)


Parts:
BATT1: KEYSTONE_54KEYSTONE_2; KEYSTONE_V2
C2: 10uF; 0603
C9: 2.2uF; 0603
C10: 10nF; 0603
C11, C14: 47uF; 0603
L1: LQH3NPN100MMEL; INDPM3030X150N
Q1: 2.5A/30V/105mΩ; SOT23-3
R5: 365k; 0603
R7: 10M; 0603
R18: 2M; 0603
U4: LTC3106EUDC#TRPBF; QFN50P400X300X80-21N

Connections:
BATT_IN: BATT1.P$1 (+), BATT1.P$2 (+), BATT1.P$3 (+), Q1.3 (D)
GND: BATT1.P$4 (-), BATT1.P$5 (-), BATT1.P$6 (-), C2.2, C9.2, C10.2, C11.2, C14.2, Q1.1 (G), R5.1, U4.6 (OS2), U4.9 (SS2), U4.10 (SS1), U4.15 (GND), U4.21 (GND); also elsewhere on the board
unnamed: L1.1, U4.18 (SW1)
unnamed: L1.2, U4.17 (SW2)
unnamed: R7.1, U4.7 (PGOOD)
unnamed: C9.1, U4.3 (VAUX)
unnamed: C2.1, R18.2, U4.16 (VIN)
unnamed: R5.2, R18.1, U4.13 (RUN)
VCC: C10.1, U4.4 (VCC), U4.5 (OS1), U4.8 (MPP), U4.11 (PRI), U4.12 (ILIMSEL)
VDD: C14.1, R7.2, U4.2 (VOUT); also elsewhere on the board
V_BATT: C11.1, Q1.2 (S), U4.14 (ENVSTR), U4.19 (VSTORE), U4.20 (VCAP)

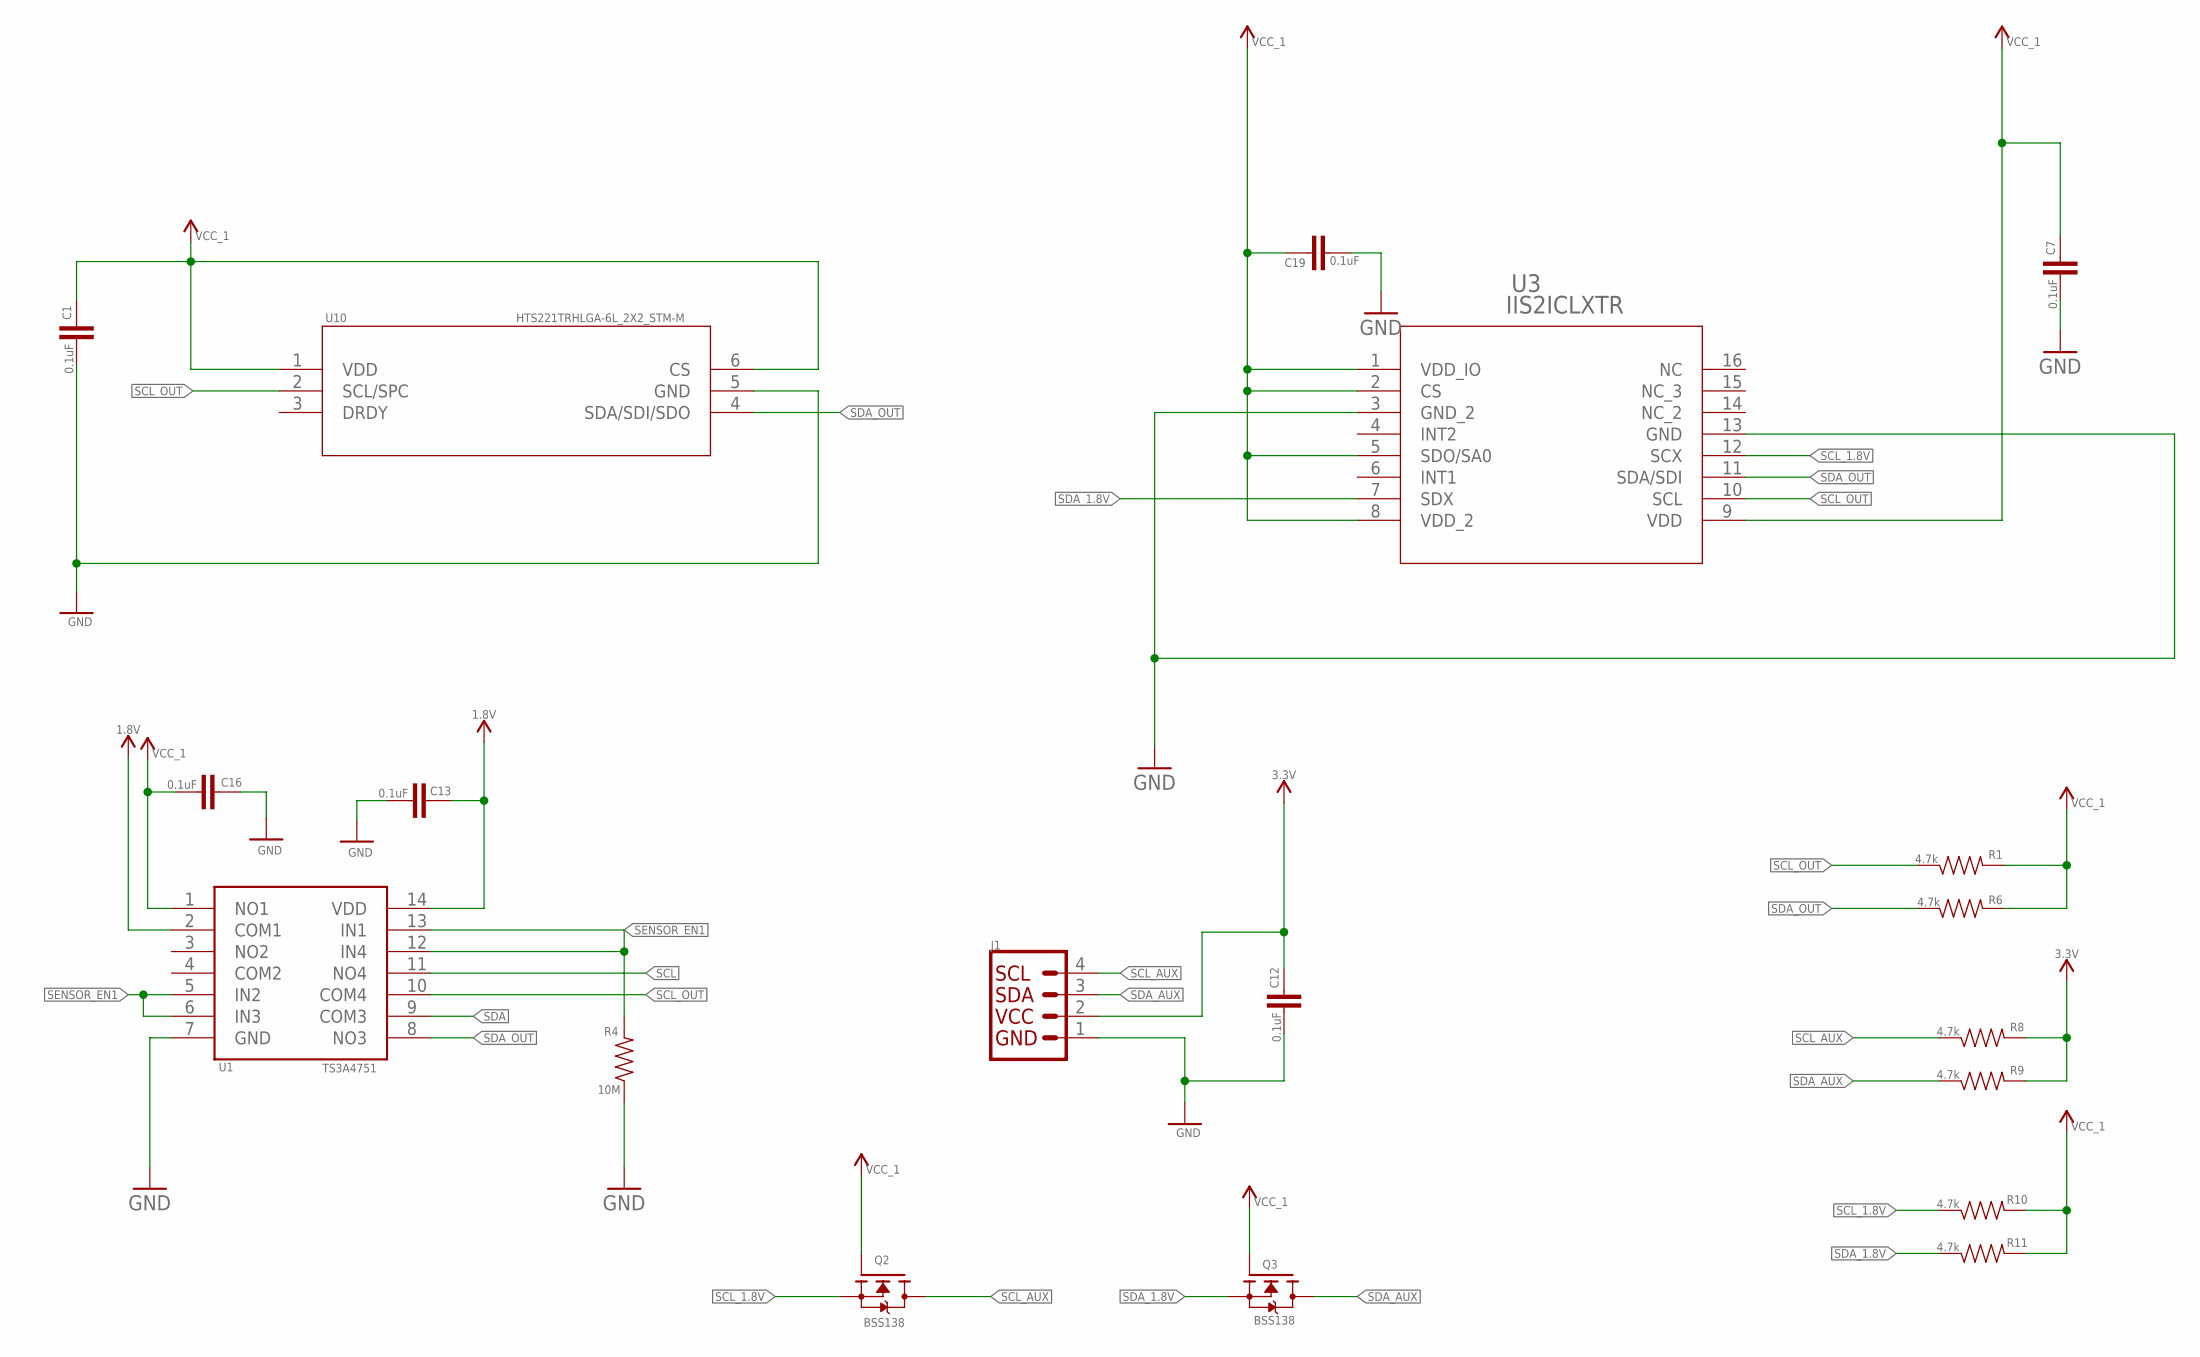
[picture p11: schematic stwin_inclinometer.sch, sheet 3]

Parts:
C1, C7, C12, C13, C16, C19: 0.1uF; 0603
J1: I2C_STANDARD; 1X04
Q2, Q3: BSS138; SOT95P240X111-3N
R1, R6, R8, R9, R10, R11: 4.7k; 0603
R4: 10M; 0603
U1: TS3A4751; 14_PIN
U3: IIS2ICLXTR; QFN_ICLX_STM
U10: HTS221TRHLGA-6L_2X2_STM-M; HLGA-6L_2X2_STM-M

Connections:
1.8V: C13.1, U1.2 (COM1), U1.14 (VDD); also elsewhere on the board
3.3V: C12.1, J1.2, R8.2, R9.2; also elsewhere on the board
GND: C1.2, C7.2, C12.2, C13.2, C16.1, C19.2, J1.1, R4.1, U1.7 (GND), U3.3 (GND_2), U3.13 (GND), U10.5 (GND); also elsewhere on the board
SCL: U1.11 (NO4); also elsewhere on the board
SCL_1.8V: Q2.2 (S), R10.1, U3.12 (SCX)
SCL_AUX: J1.4, Q2.3 (D), R8.1
SCL_OUT: R1.1, U1.10 (COM4), U3.10 (SCL), U10.2 (SCL/SPC)
SDA: U1.9 (COM3); also elsewhere on the board
SDA_1.8V: Q3.2 (S), R11.1, U3.7 (SDX)
SDA_AUX: J1.3, Q3.3 (D), R9.1
SDA_OUT: R6.1, U1.8 (NO3), U3.11 (SDA/SDI), U10.4 (SDA/SDI/SDO)
SENSOR_EN1: R4.2, U1.5 (IN2), U1.6 (IN3), U1.12 (IN4), U1.13 (IN1); also elsewhere on the board
VCC_1: C1.1, C7.1, C16.2, C19.1, Q2.1 (G), Q3.1 (G), R1.2, R6.2, R10.2, R11.2, U1.1 (NO1), U3.1 (VDD_IO), U3.2 (CS), U3.5 (SDO/SA0), U3.8 (VDD_2), U3.9 (VDD), U10.1 (VDD), U10.6 (CS)

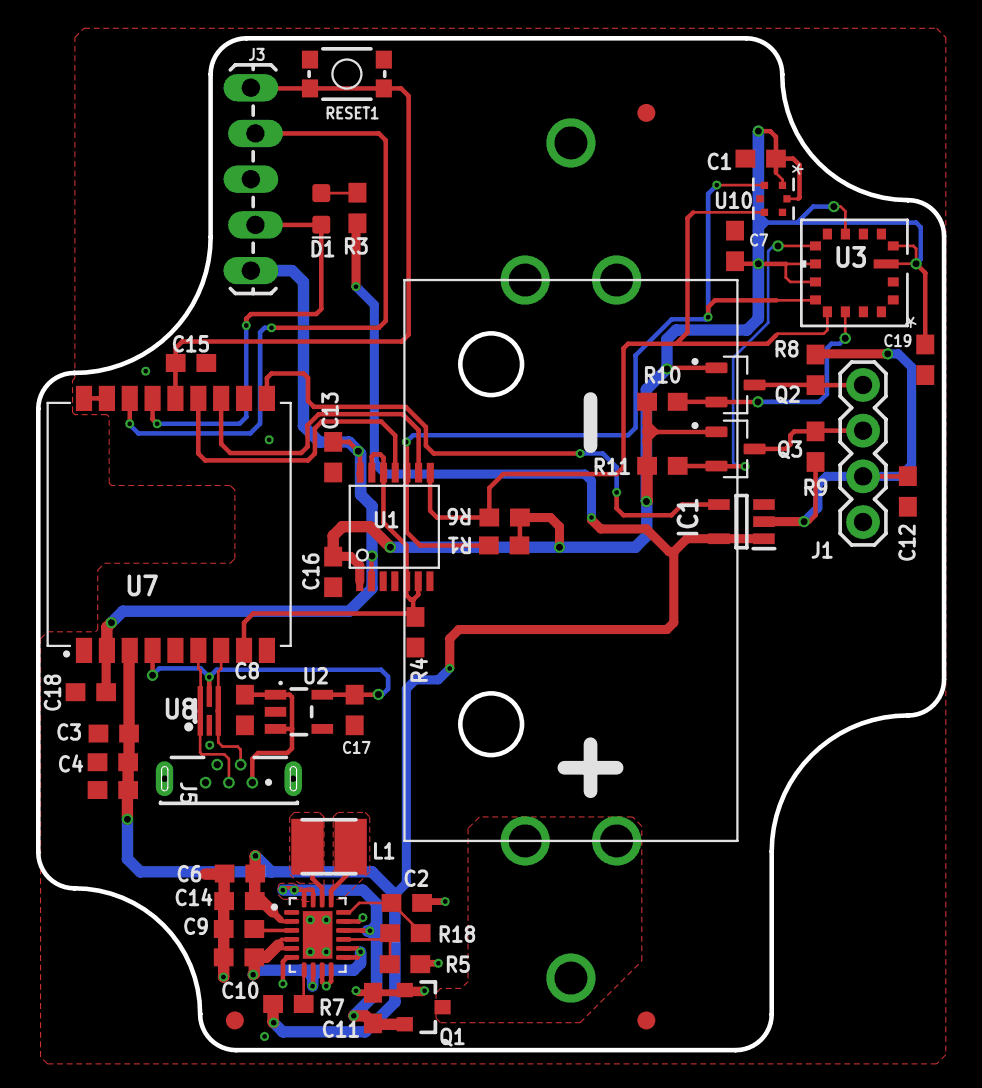
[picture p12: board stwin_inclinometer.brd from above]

Board: 2 copper layers, 50.3 x 56.2 mm, 51 parts (0 on the bottom side), 34 nets.

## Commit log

2020-12-07 Design files check-in
    [stwin_bluetooth_iNEMO.brd, stwin_bluetooth_iNEMO.sch, stwin_inclinometer.brd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]
2020-12-08 Uploading gerber files
    [zigbee_iNEMO.brd, zigbee_iNEMO.sch]
2020-12-22 Check-in of BoM files
    [stwin_bluetooth_iNEMO.csv, stwin_bluetooth_iNEMO.xlsx, stwin_inclinometer.csv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]

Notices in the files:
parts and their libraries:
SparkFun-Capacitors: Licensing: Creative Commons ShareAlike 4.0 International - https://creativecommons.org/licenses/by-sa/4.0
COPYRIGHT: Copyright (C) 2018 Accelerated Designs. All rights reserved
